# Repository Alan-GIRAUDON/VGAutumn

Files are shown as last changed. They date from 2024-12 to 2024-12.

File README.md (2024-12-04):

# VGAutumn

# Summary of the project

VGAutumn is a RP2040 VGA joystick PCB. This board allows to play different game using its VGA output and its inputs (joystick, buttons).

## Schematics

schematics

## Features

- Micro-USB connector to power and program the board
- LDO converter, 3V3 for the RP2040, Flash memory, SD card and joystick and LED
- 16 MB flash memory
- Boot button to put the RP2040 in USB storage mode
- VGA connector linked to the RP2040 through a resistor ladder (cheap DAC)
- Joystick (vertical, horizontal and pushable) with two buttons
- micro-SD card reader
- 3 LEDS, White, Blue LED and a Red power LED
- Expose the debug pins

## PCB caracteristics

The PCB is a two layer board with single-sided assembly, the thinnest trace is 0.2 mm and the vias have a 0.7 mm diameter ring and a 0.3 mm hole. The USB traces are as short and as thick as possible to be as close as possible to the 90 $\Omega$ impedance of the JLCPCB two-layer board stackup.

## Board results :

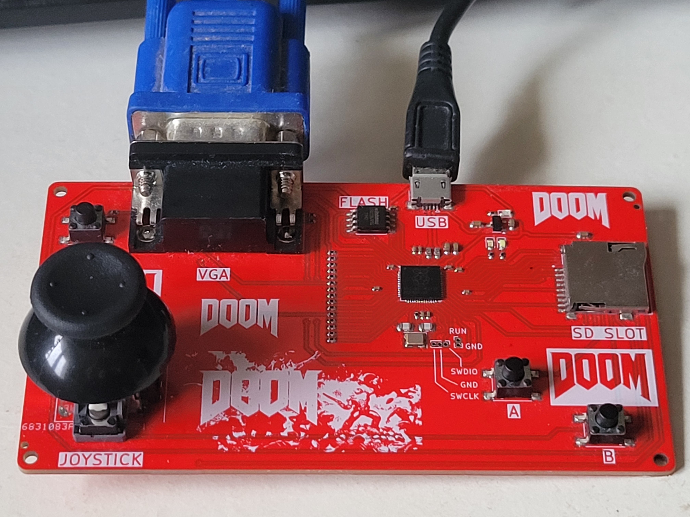
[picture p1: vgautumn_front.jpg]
PCB_front

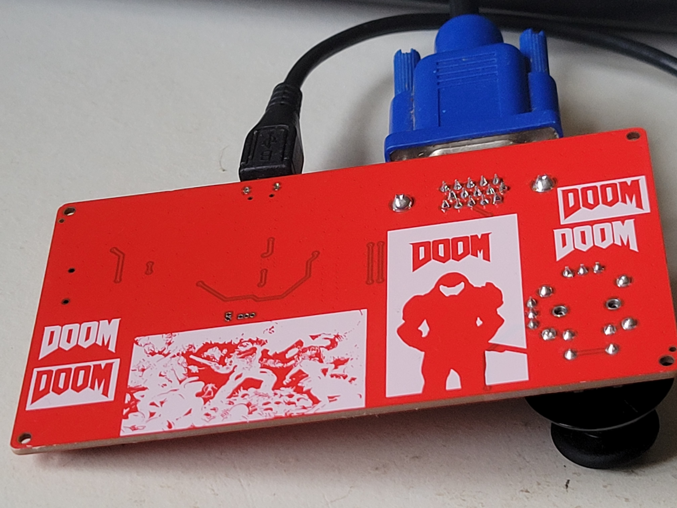
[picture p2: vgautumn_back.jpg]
PCB_back


## Programming

The board can be programmed in Python through the Thonny IDE, in C/C++ with CMake (VS Code, NVIM) and even (not tested) with the Arduino IDE.

The "pico-playgrounds" and "pico-examples" given by Raspberry are a great way to test the VGA output and the Joystick.

To run Doom on the board, we can use the [RP2040-doom](https://github.com/kilograham/rp2040-doom) by kilograham (congratulations to him for this amazing work), the first release of "doom1-usb.uf2" work out of the box because the board use the default VGA pins.

Note : To make Doom responds to Joystick and buttons inputs, you need to modify the code in the pico folder.

## Current Issues and TO DO list

- Doom use the SDL2 library to get input from USB HID devices (Keyboard, Joystick) while we use GPIO's to connect the joystick and buttons. It means that the code need to modified to get the inputs.
- Doom needs more than 3 buttons and a joystick to be fully playable, future versions could include an additional USB port for power to connect a keyboard to the first one
- The board doesn't implement nor expose any way to have sound output
- The micro-SD reader isn't used by RP2040-doom, it could be removed
- The joystick used works great on its vertical motion but the horizontal one is not smooth and the output values aren't in the same range
- The modified (ugly) version of RP2040-doom wich detect joystick and buttons should be uploaded soon (only works in the main menu for some reason)

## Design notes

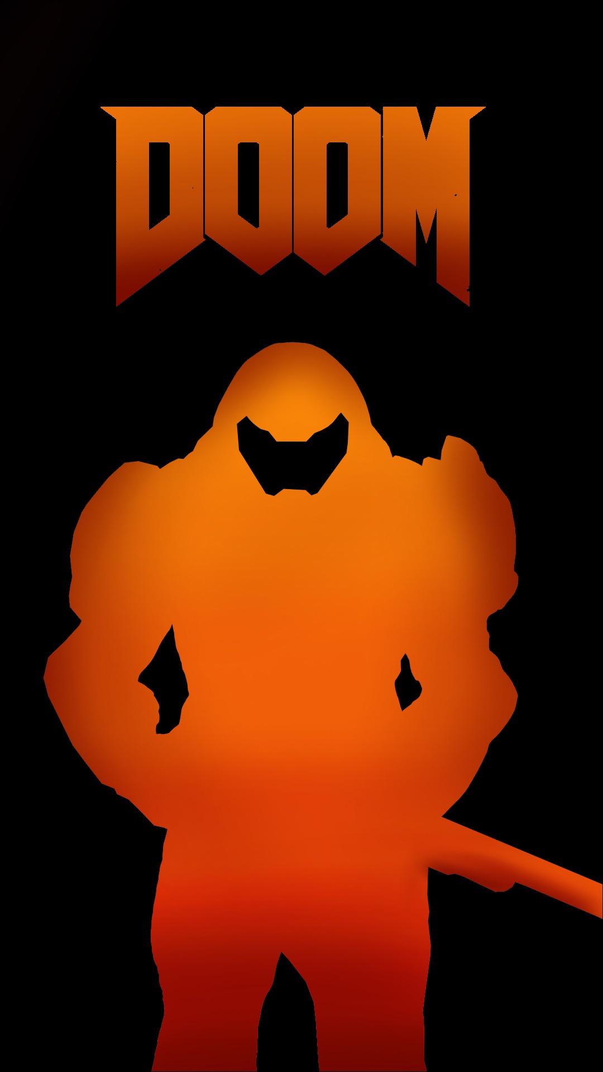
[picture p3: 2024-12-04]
doom_mini.jpg

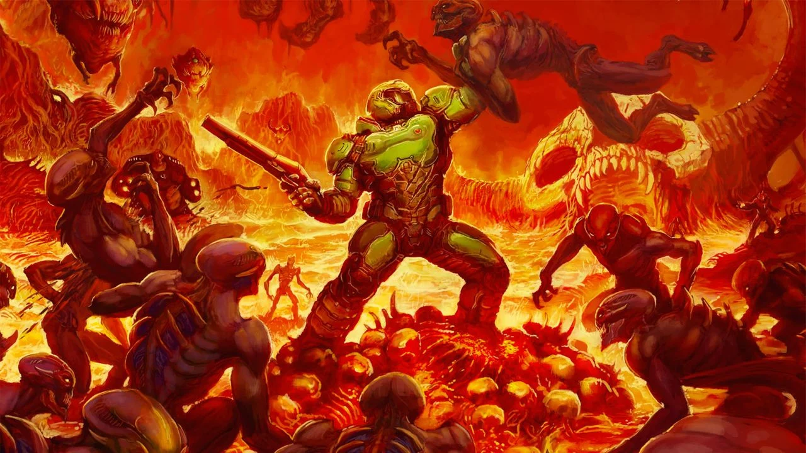
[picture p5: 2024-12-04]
doom_fight.png

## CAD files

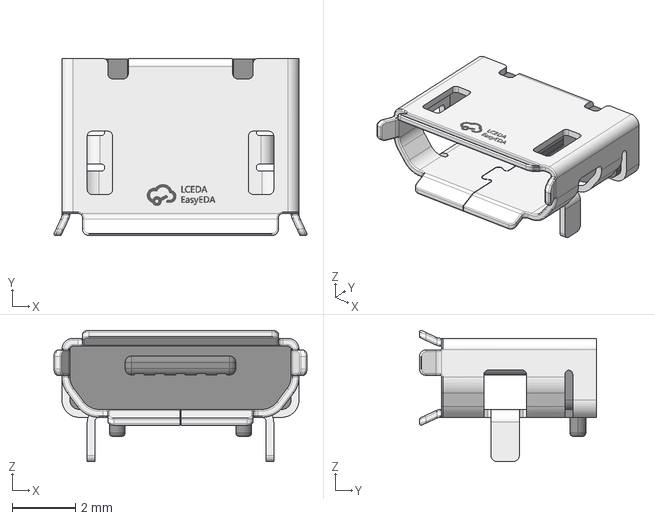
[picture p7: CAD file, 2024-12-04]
3dmodels/USB_Micro.step
8.00 x 5.60 x 4.15 mm

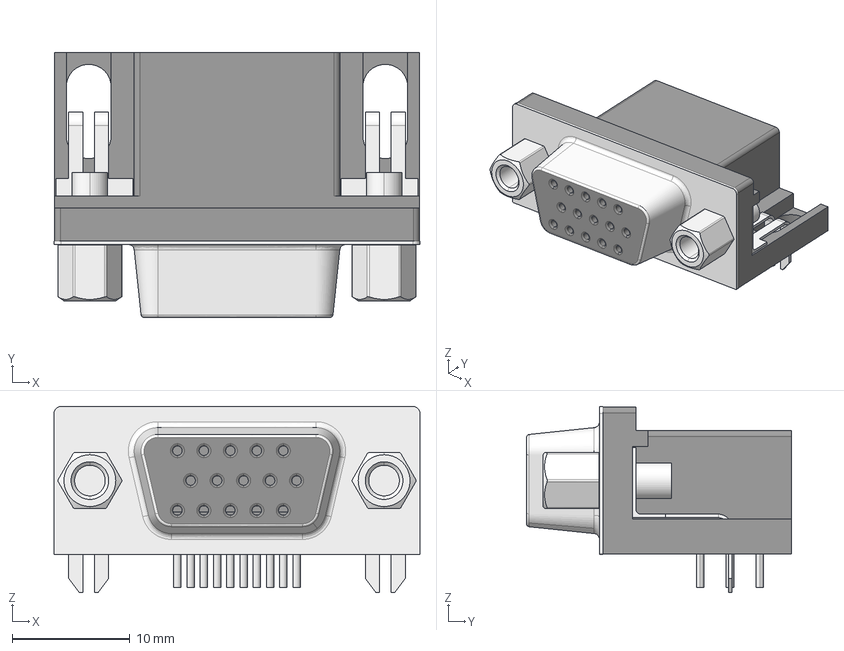
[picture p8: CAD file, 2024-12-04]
3dmodels/VGA_Conn.step
31.1 x 22.5 x 15.8 mm

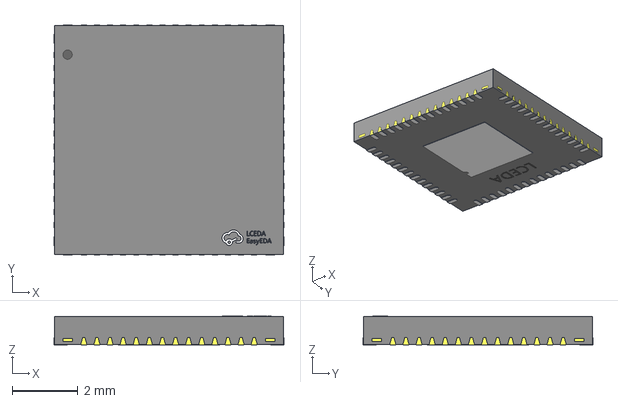
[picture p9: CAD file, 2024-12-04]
3dmodels/RP2040.step
7.02 x 7.02 x 0.88 mm

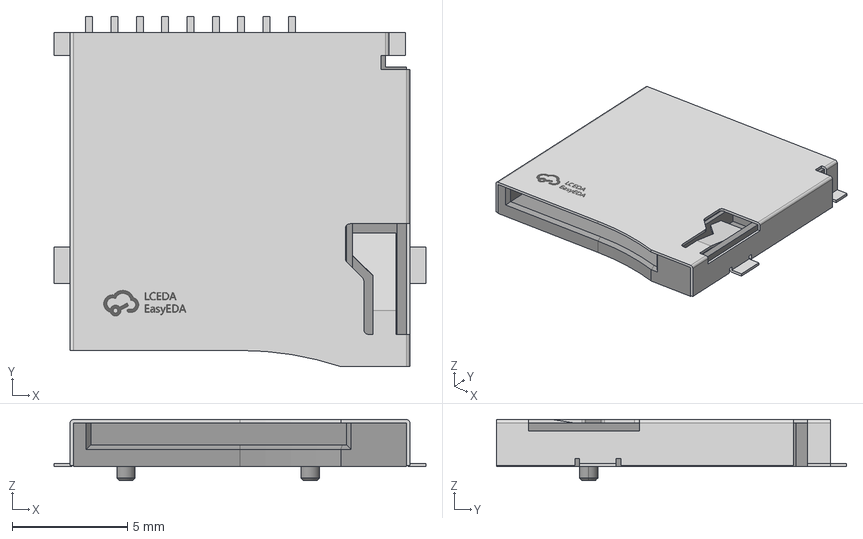
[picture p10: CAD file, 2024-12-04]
3dmodels/SD_card.step
16.2 x 15.2 x 2.65 mm

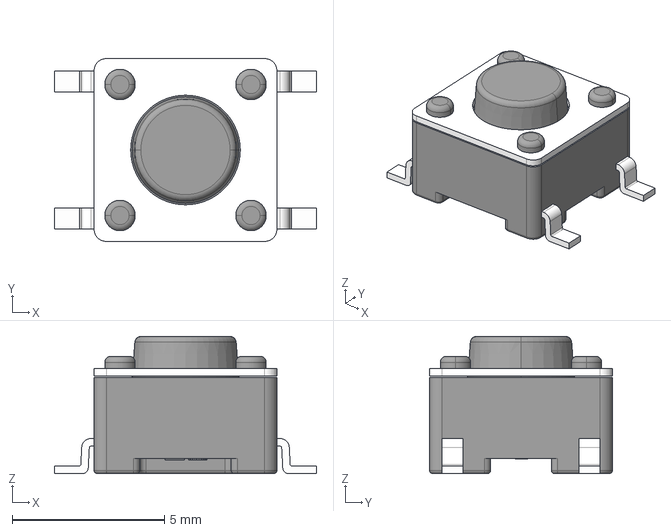
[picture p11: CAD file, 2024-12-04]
3dmodels/Switch.step
8.60 x 6.00 x 4.50 mm

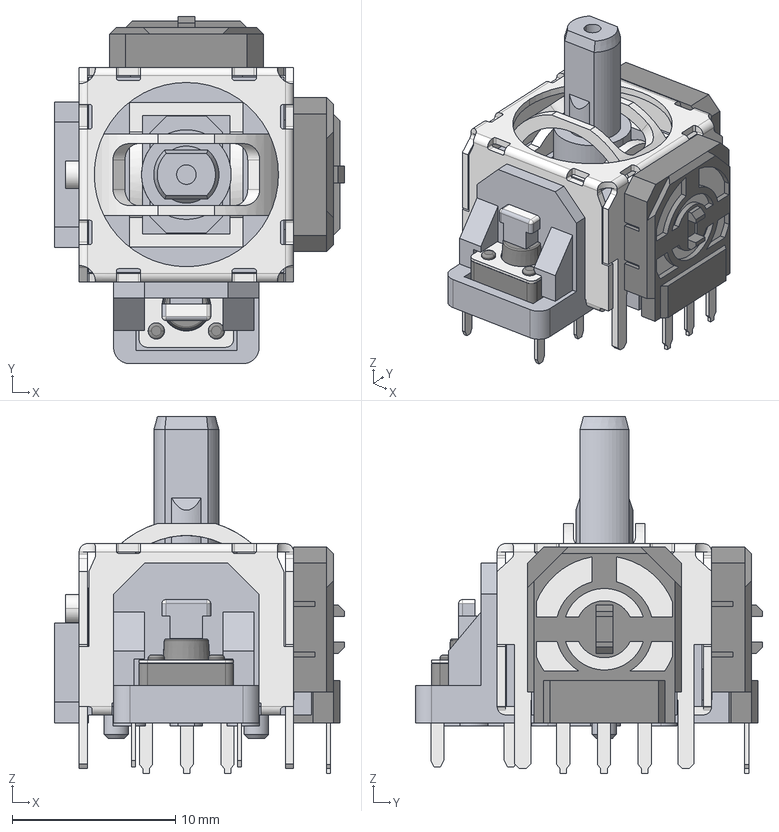
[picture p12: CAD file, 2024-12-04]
3dmodels/Thumbstick.step
17.8 x 21.3 x 21.9 mm

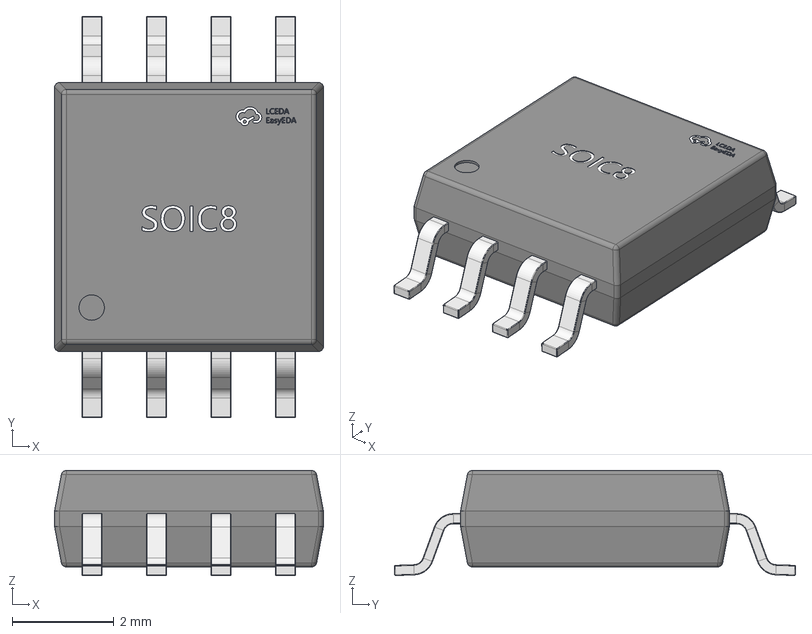
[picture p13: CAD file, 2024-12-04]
3dmodels/W25Q128JVS.step
5.30 x 7.91 x 2.07 mm

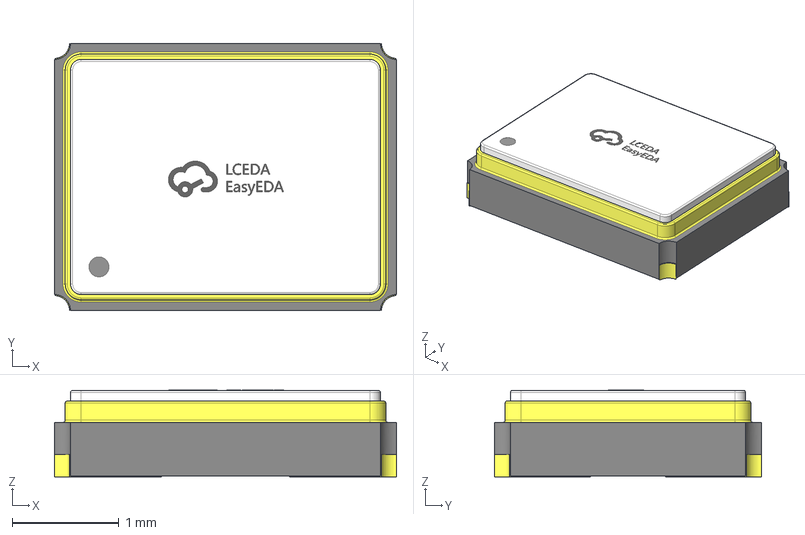
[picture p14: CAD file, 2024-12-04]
3dmodels/Crystal.step
3.20 x 2.50 x 0.811 mm

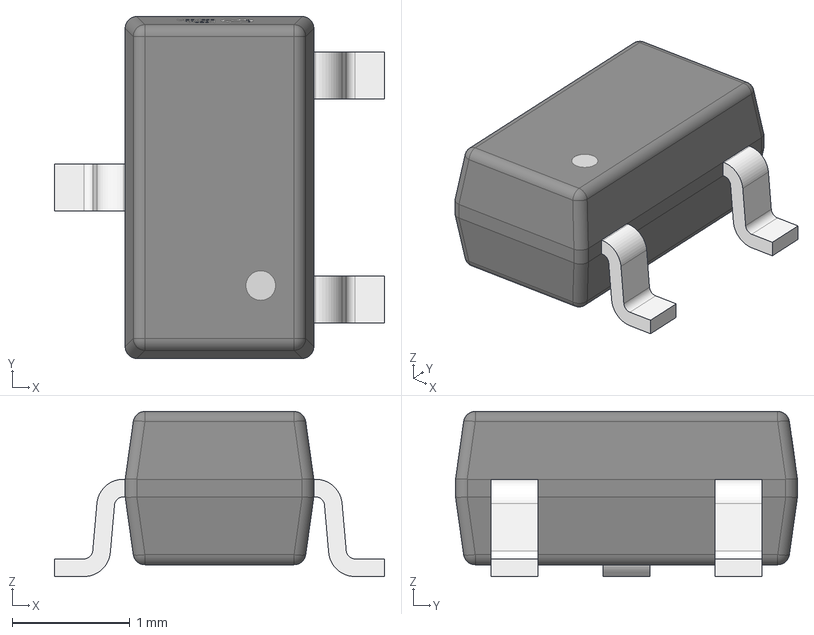
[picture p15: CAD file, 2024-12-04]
3dmodels/XC6206P332MR.step
2.80 x 2.90 x 1.40 mm

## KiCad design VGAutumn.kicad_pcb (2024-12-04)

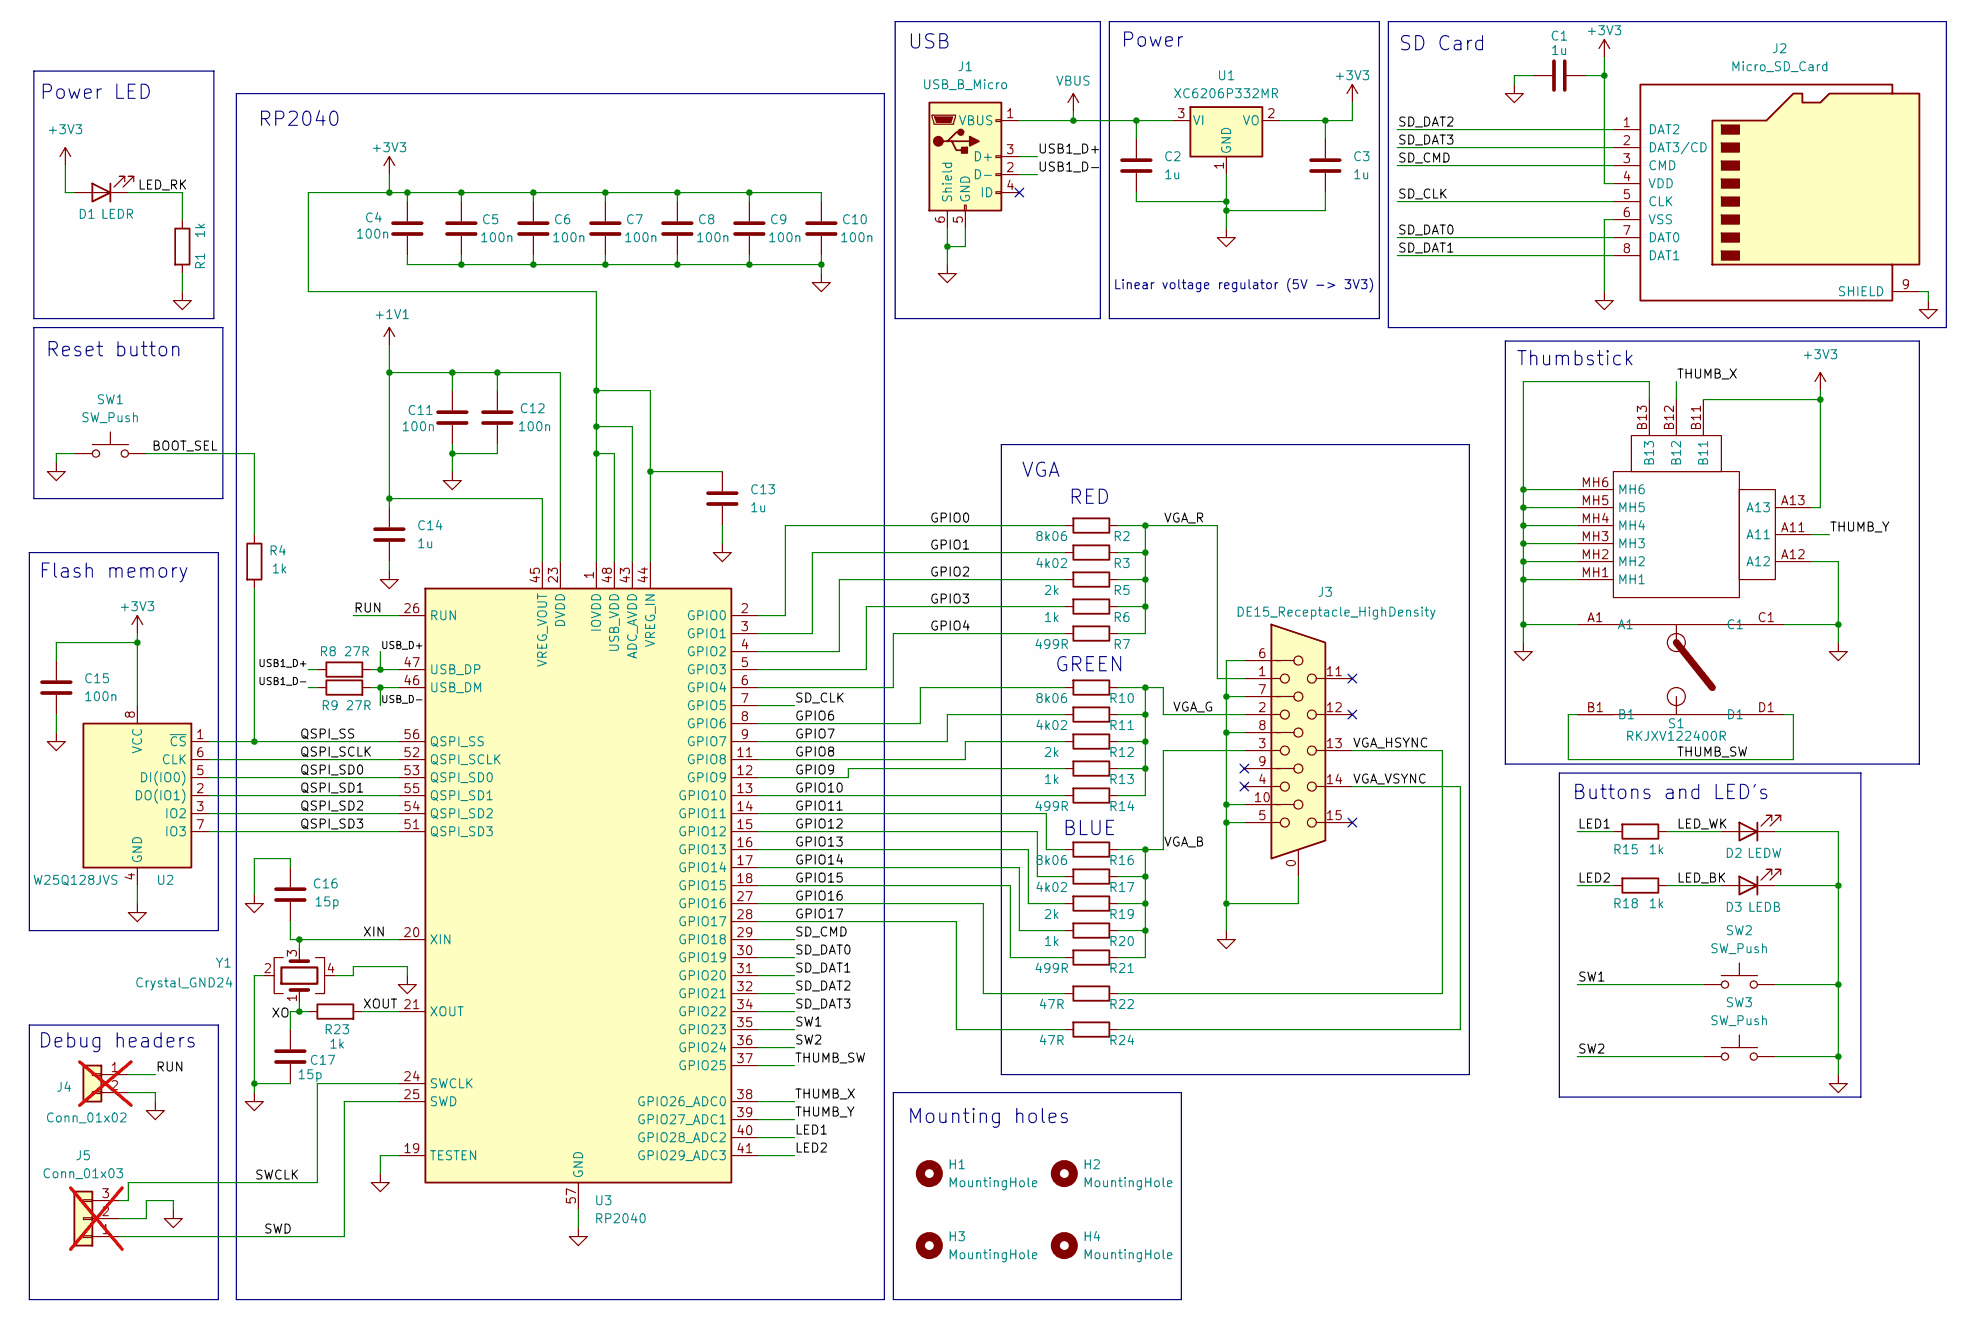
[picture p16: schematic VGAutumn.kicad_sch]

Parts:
C1, C2, C3, C13, C14: 1u; C_0603_1608Metric; LCSC Part # C15849
C4, C5, C6, C7, C8, C9, C10, C11, C12, C15: 100n; C_0402_1005Metric; LCSC Part # C307331
C16, C17: 15p; C_0805_2012Metric; LCSC Part # C107110
D1: LEDR; LED_0603_1608Metric; LCSC Part # C2286
D2: LEDW; LED_0603_1608Metric; LCSC Part # C2290
D3: LEDB; LED_0603_1608Metric; LCSC Part # C2986058
H1, H2, H3, H4: MountingHole; MountingHole_2.2mm_M2; LCSC Part # X
J1: USB_B_Micro; USB_Micro-B_XKB_U254-051T-4BH83-F1S; LCSC Part # C393940
J2: Micro_SD_Card; GCT_MEM2075-00-140-01-A; LCSC Part # C393941
J3: DE15_Receptacle_HighDensity; VGA; LCSC Part # C379814
J4: Conn_01x02; PinHeader_1x02_P1.00mm_Vertical; LCSC Part # X; not fitted
J5: Conn_01x03; PinHeader_1x03_P1.00mm_Vertical; LCSC Part # X; not fitted
R1, R4, R6, R13, R15, R18, R20, R23: 1k; R_0402_1005Metric; LCSC Part # C11702
R2, R10, R16: 8k06; R_0402_1005Metric; LCSC Part # C276278
R3, R11, R17: 4k02; R_0402_1005Metric; LCSC Part # C43251
R5, R12, R19: 2k; R_0402_1005Metric; LCSC Part # C4109
R7, R14, R21: 499R; R_0402_1005Metric; LCSC Part # C4125
R8, R9: 27R; R_0603_1608Metric; LCSC Part # C25190
R22, R24: 47R; R_0402_1005Metric; LCSC Part # C25118
S1: RKJXV122400R; LCSC Part # C146170
SW1, SW2, SW3: SW_Push; SW_Push_1P1T_NO_6x6mm_H9.5mm; LCSC Part # C5127964
U1: XC6206P332MR; SOT-23-3; LCSC Part # C5446
U2: W25Q128JVS; SOIC-8_5.23x5.23mm_P1.27mm; LCSC Part # C97521
U3: RP2040; QFN-56-1EP_7x7mm_P0.4mm_EP3.2x3.2mm; LCSC Part # C2040
Y1: Crystal_GND24; Crystal_SMD_SeikoEpson_FA238-4Pin_3.2x2.5mm; LCSC Part # C9002

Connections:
+1V1: C11.2, C12.2, C14.1, U3.23 (DVDD), U3.45 (VREG_VOUT), U3.50 (DVDD)
+3V3: C1.2, C3.1, C4.2, C5.2, C6.2, C7.2, C8.2, C9.2, C10.2, C13.1, C15.1, D1.2 (A), J2.4 (VDD), S1.A13, S1.B11, U1.2 (VO), U2.8 (VCC), U3.1 (IOVDD), U3.10 (IOVDD), U3.22 (IOVDD), U3.33 (IOVDD), U3.42 (IOVDD), U3.43 (ADC_AVDD), U3.44 (VREG_IN), U3.48 (USB_VDD), U3.49 (IOVDD)
/BOOT_SEL: R4.1, SW1.2
/GPIO0: R2.2, U3.2 (GPIO0)
/GPIO1: R3.2, U3.3 (GPIO1)
/GPIO2: R5.2, U3.4 (GPIO2)
/GPIO3: R6.2, U3.5 (GPIO3)
/GPIO4: R7.2, U3.6 (GPIO4)
/GPIO6: R10.2, U3.8 (GPIO6)
/GPIO7: R11.2, U3.9 (GPIO7)
/GPIO8: R12.2, U3.11 (GPIO8)
/GPIO9: R13.2, U3.12 (GPIO9)
/GPIO10: R14.2, U3.13 (GPIO10)
/GPIO11: R16.2, U3.14 (GPIO11)
/GPIO12: R17.2, U3.15 (GPIO12)
/GPIO13: R19.2, U3.16 (GPIO13)
/GPIO14: R20.2, U3.17 (GPIO14)
/GPIO15: R21.2, U3.18 (GPIO15)
/GPIO16: R22.2, U3.27 (GPIO16)
/GPIO17: R24.2, U3.28 (GPIO17)
/LED1: R15.2, U3.40 (GPIO28_ADC2)
/LED2: R18.2, U3.41 (GPIO29_ADC3)
/LED_BK: D3.2 (A), R18.1
/LED_RK: D1.1 (K), R1.1
/LED_WK: D2.2 (A), R15.1
/QSPI_SCLK: U2.6 (CLK), U3.52 (QSPI_SCLK)
/QSPI_SD0: U2.5 (DI(IO0)), U3.53 (QSPI_SD0)
/QSPI_SD1: U2.2 (DO(IO1)), U3.55 (QSPI_SD1)
/QSPI_SD2: U2.3 (IO2), U3.54 (QSPI_SD2)
/QSPI_SD3: U2.7 (IO3), U3.51 (QSPI_SD3)
/QSPI_SS: R4.2, U2.1 (~CS), U3.56 (QSPI_SS)
/RUN: J4.1, U3.26 (RUN)
/SD_CLK: J2.5 (CLK), U3.7 (GPIO5)
/SD_CMD: J2.3 (CMD), U3.29 (GPIO18)
/SD_DAT0: J2.7 (DAT0), U3.30 (GPIO19)
/SD_DAT1: J2.8 (DAT1), U3.31 (GPIO20)
/SD_DAT2: J2.1 (DAT2), U3.32 (GPIO21)
/SD_DAT3: J2.2 (DAT3/CD), U3.34 (GPIO22)
/SW1: SW2.1, U3.35 (GPIO23)
/SW2: SW3.1, U3.36 (GPIO24)
/SWCLK: J5.3, U3.24 (SWCLK)
/SWD: J5.1, U3.25 (SWD)
/THUMB_SW: S1.B1, S1.D1, U3.37 (GPIO25)
/THUMB_X: S1.B12, U3.38 (GPIO26_ADC0)
/THUMB_Y: S1.A11, U3.39 (GPIO27_ADC1)
/USB1_D+: J1.3 (D+), R8.1
/USB1_D-: J1.2 (D-), R9.1
/USB_D+: R8.2, U3.47 (USB_DP)
/USB_D-: R9.2, U3.46 (USB_DM)
/VGA_B: J3.3, R16.1, R17.1, R19.1, R20.1, R21.1
/VGA_G: J3.2, R10.1, R11.1, R12.1, R13.1, R14.1
/VGA_HSYNC: J3.13, R22.1
/VGA_R: J3.1, R2.1, R3.1, R5.1, R6.1, R7.1
/VGA_VSYNC: J3.14, R24.1
/XIN: C16.1, U3.20 (XIN), Y1.3
/XO: C17.1, R23.1, Y1.1
/XOUT: R23.2, U3.21 (XOUT)
GND: C1.1, C2.2, C3.2, C4.1, C5.1, C6.1, C7.1, C8.1, C9.1, C10.1, C11.1, C12.1, C13.2, C14.2, C15.2, C16.2, C17.2, D2.1 (K), D3.1 (K), J1.5 (GND), J1.6 (Shield), J2.6 (VSS), J2.9 (SHIELD), J3.0, J3.5, J3.6, J3.7, J3.8, J3.10, J4.2, J5.2, R1.2, S1.A1, S1.A12, S1.B13, S1.C1, S1.MH1, S1.MH2, S1.MH3, S1.MH4, S1.MH5, S1.MH6, SW1.1, SW2.2, SW3.2, U1.1 (GND), U2.4 (GND), U3.19 (TESTEN), U3.57 (GND), Y1.2, Y1.4
VBUS: C2.1, J1.1 (VBUS), U1.3 (VI)

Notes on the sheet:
GREEN
Debug headers
Power
Reset button
SD Card
Power LED
USB
BLUE
Flash memory
Buttons and LED's
VGA
Thumbstick
Mounting holes
Linear voltage regulator (5V -> 3V3)
RP2040
RED

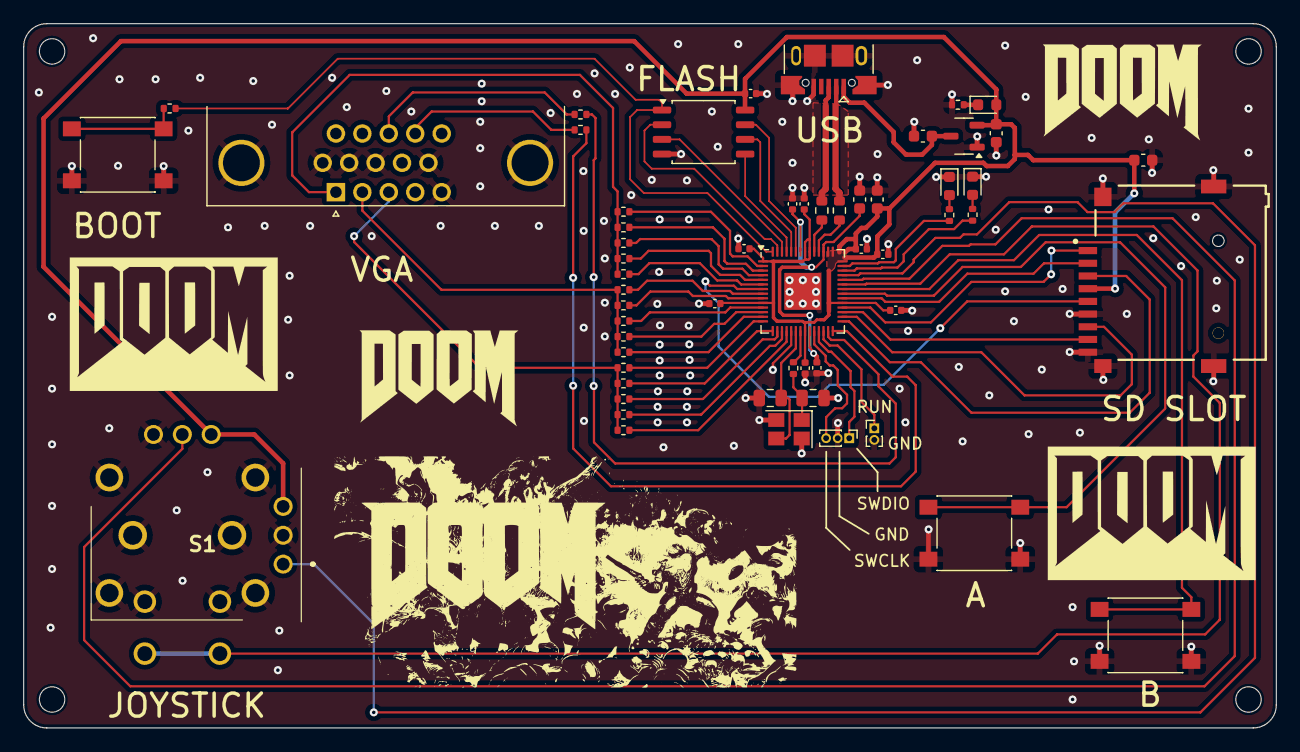
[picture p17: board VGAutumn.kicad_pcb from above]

Board: 2 copper layers, 108.5 x 61.0 mm, 61 parts (0 on the bottom side), 59 nets.
